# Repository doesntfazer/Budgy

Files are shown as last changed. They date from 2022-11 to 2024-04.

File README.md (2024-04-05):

# Budgy Keyboard

Budgy is a split 34 key keyboard powered by a Raspberry Pi Pico and diode-less.

### Builds:
Budgy  

[Build by: Jakob Edvarsson](https://github.com/JakobEdvardsson)
Budgy

## What you need to build a Budgy

| Component | Amount |
|--|--|
| Reversible Budgy PCB | x2 |
| Raspberry Pi Pico w/headers | x2 |
| Cherry Switches (5 pin recommended) | x34 |
| Keycaps | x34 |
| TRRS Cable | x1 |
| PJ-320A TRRS Jacks | x2 |
| Rubber Bumpers | x8 |

- Solder headers to both raspberry pi Pico's

- On the left hand board, solder the Raspberry Pi Pico facing up and to the rightmost set of pins. If you are still unsure reference the photo above.

- Like in the previous step above, on the right hand side of the board, solder the Pico to the rightmost set of pins. Use the photo for reference. 

- Solder the TRRS Jacks to the top of each side, again reference photo. 

- I recommended at this point, you test the board to make sure everything is functioning. Plug in each side of the board while holding down the reset pin on the top of the board. Drag and drop the UF2 files from [here.](https://github.com/doesntfazer/Keyboard-Dweebs-Firmware-repository/tree/main/VIAL-QMK/budgy) You need to do this on both boards.

- Connect the halves using a TRRS cable, and short each key using some tweezers or a piece of wire. These files use [Vial QMK. You can download this app and use it to configure your keyboard.](https://get.vial.today/download/)

- If everything is working correctly you can proceed to solder in all of the switches, add your keycaps, and put a rubber bumper in each corner on the bottom of each pcb, then start typing away.

### Firmware

Here are links to a couple of different firmware available for the Budgy keyboard. 

- VIAL [here.](https://github.com/doesntfazer/Keyboard-Dweebs-Firmware-repository/tree/main/VIAL-QMK/budgy)
- KMK - [here.](https://github.com/KMKfw/kmk_firmware/tree/master/boards/budgy)
- QMK - [here.](https://github.com/qmk/qmk_firmware/tree/master/keyboards/budgy)

#### Some things to note. 
- It's okay if you don't have 5 pin Cherry switches. If you bend one of the pins on the switch a bit, they should hold in place when you flip the board over.

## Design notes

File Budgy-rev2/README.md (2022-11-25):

# Budgy
 Split 34 key keyboard powered by a raspberry pi pico and QMK

This keyboard is Diodeless. 

DO NOT DOWNLOAD OR PRINT REV 2. I have yet to do any testing. But I noticed a major flaw with the current design. The power supply voltage for the SK6812MINI-E that I am planning to use is 5v (or +3.7~+5.5), and the logic input is 3.3v. I would just use the 3v3 out. But in testing the SK6812MINI-E will not light up under such low power. 

I have added in a voltage divider using 10k + 30k resistor's in an attempt to fix this. This should provide Just enough power (3.75v) to the SK6812MINI-E supply voltage, and be withing the operating range (+-.5v) of the logic input. Although I believe that this fix might work, I don't think that this is the best solution to the problem. 

Another issue is that the VBUS on a rp2040 is directly connected to the 5v usb pin. Some issues can come from this, one being that the power coming from usb is not always consistant. If it doesn't output exactly 5v-5.05v, It will likely either not light, or not be within operating range of the logic input. 

I am going to put rev2 on the backburner for now. If anyone is interested in testing it out in it's current state let me know. But I don't know if I trust it.

Build guide coming soon.

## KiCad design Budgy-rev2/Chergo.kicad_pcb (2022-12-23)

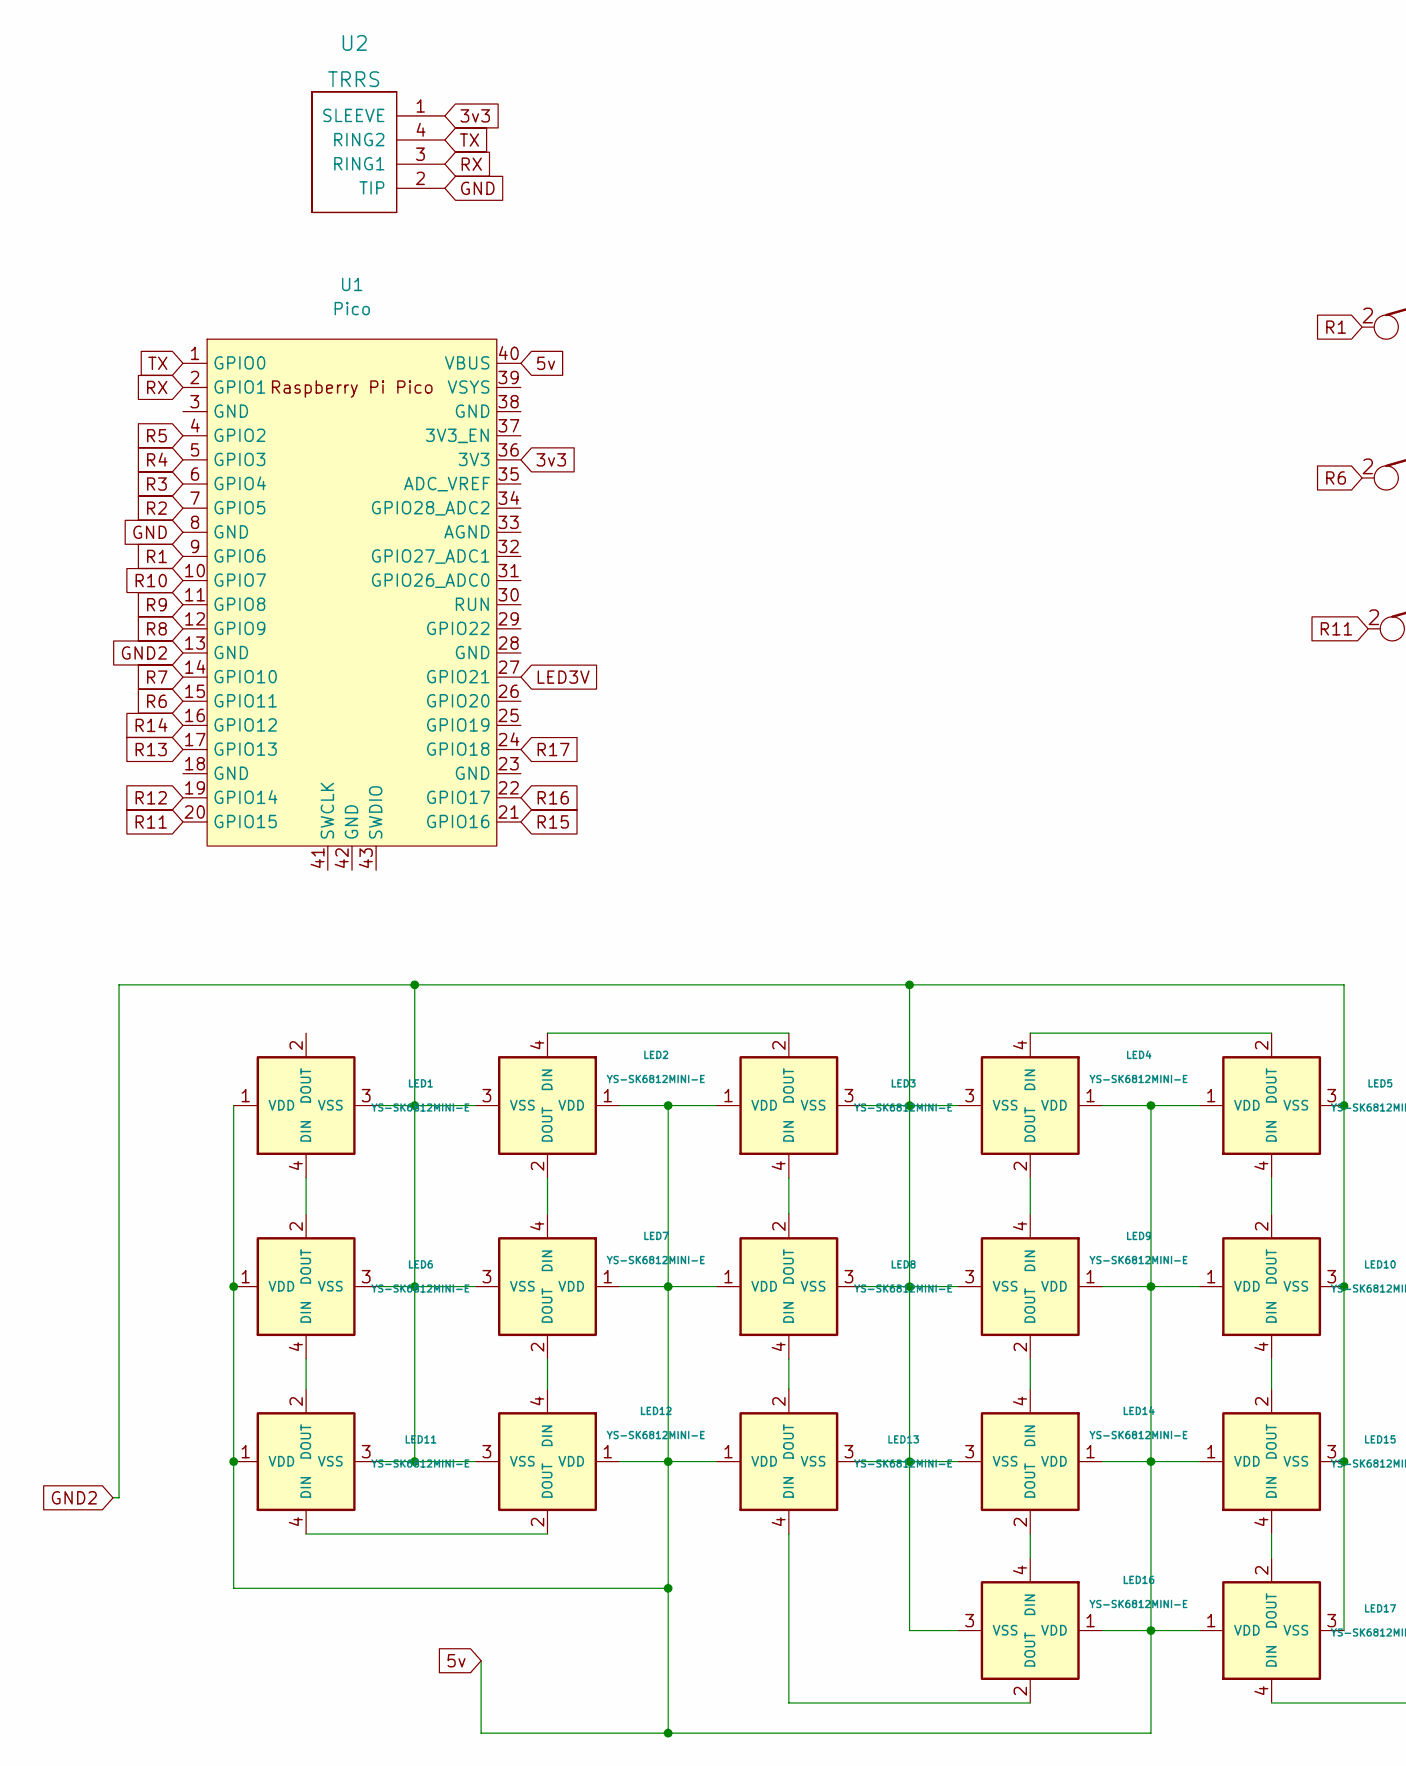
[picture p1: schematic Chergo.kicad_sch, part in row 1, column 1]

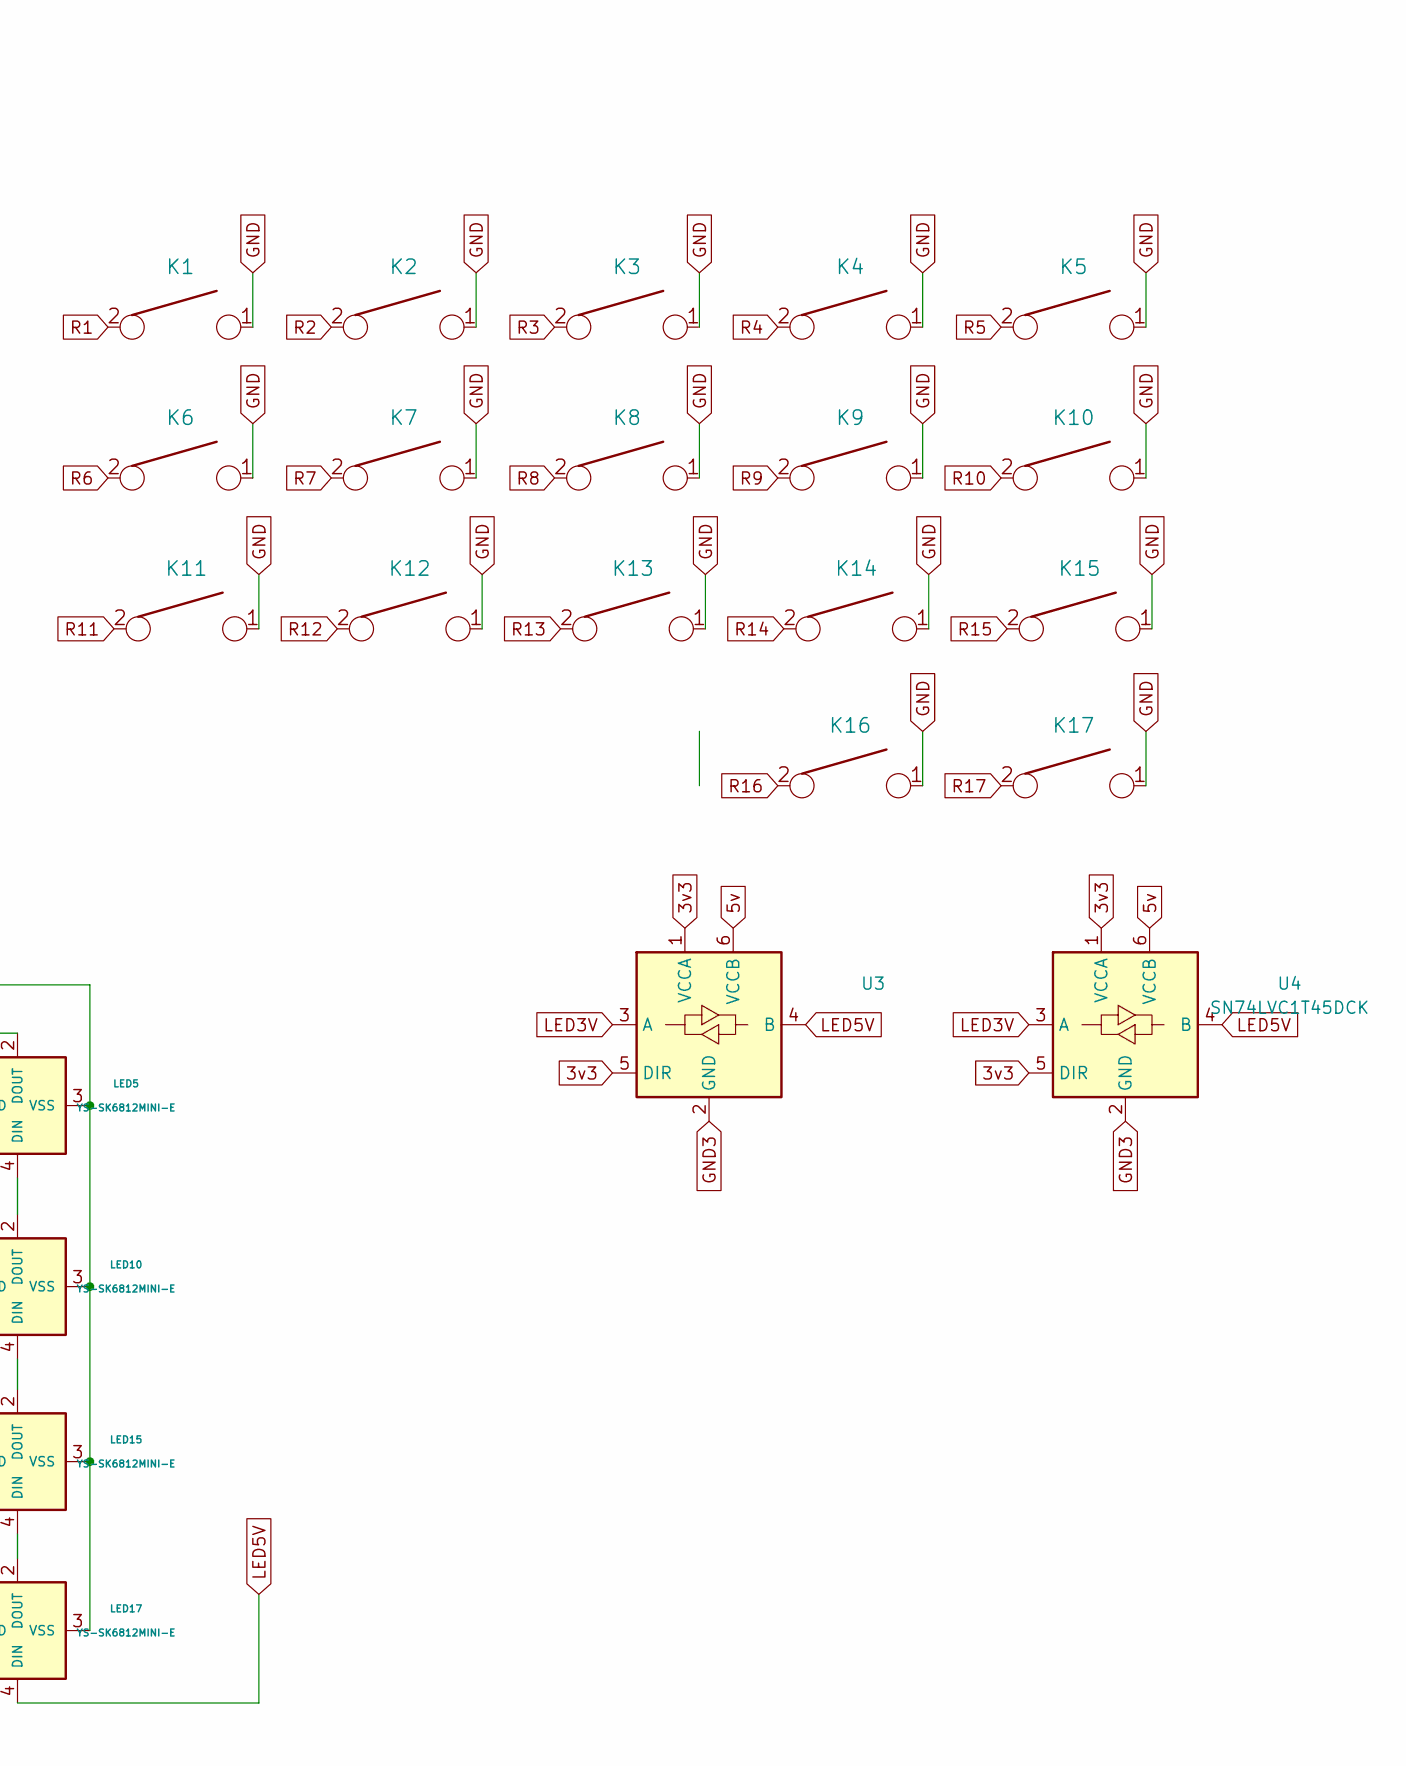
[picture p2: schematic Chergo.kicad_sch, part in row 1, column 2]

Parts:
K1, K2, K3, K4, K5, K6, K7, K8, K9, K10, K11, K12, K13, K14, K15, K16, K17: KEYSW; SW_MX_reversible
LED1, LED2, LED3, LED4, LED5, LED6, LED7, LED8, LED9, LED10, LED11, LED12, LED13, LED14, LED15, LED16, LED17: YS-SK6812MINI-E; YS-SK6812MINI-E-reversible-fix
U1: Pico; RPi_Pico_SMD_TH-REV2
U2: TRRS; TRRS-PJ-320A-rev
U3: (no value)
U4: SN74LVC1T45DCK; SOT-363_SC-70-6

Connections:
3v3: U1.36 (3V3), U2.1 (SLEEVE), U3.1 (VCCA), U3.5 (DIR), U4.1 (VCCA), U4.5 (DIR)
5v: LED1.1 (VDD), LED2.1 (VDD), LED3.1 (VDD), LED4.1 (VDD), LED5.1 (VDD), LED6.1 (VDD), LED7.1 (VDD), LED8.1 (VDD), LED9.1 (VDD), LED10.1 (VDD), LED11.1 (VDD), LED12.1 (VDD), LED13.1 (VDD), LED14.1 (VDD), LED15.1 (VDD), LED16.1 (VDD), LED17.1 (VDD), U1.40 (VBUS), U3.6 (VCCB), U4.6 (VCCB)
GND: K1.1, K2.1, K3.1, K4.1, K5.1, K6.1, K7.1, K8.1, K9.1, K10.1, K11.1, K12.1, K13.1, K14.1, K15.1, K16.1, K17.1, U1.8 (GND), U2.2 (TIP)
GND2: LED1.3 (VSS), LED2.3 (VSS), LED3.3 (VSS), LED4.3 (VSS), LED5.3 (VSS), LED6.3 (VSS), LED7.3 (VSS), LED8.3 (VSS), LED9.3 (VSS), LED10.3 (VSS), LED11.3 (VSS), LED12.3 (VSS), LED13.3 (VSS), LED14.3 (VSS), LED15.3 (VSS), LED16.3 (VSS), LED17.3 (VSS), U1.13 (GND)
GND3: U3.2 (GND), U4.2 (GND)
LED3V: U1.27 (GPIO21), U3.3 (A), U4.3 (A)
LED5V: LED17.4 (DIN), U3.4 (B), U4.4 (B)
unnamed: LED1.4 (DIN), LED6.2 (DOUT)
unnamed: LED2.2 (DOUT), LED7.4 (DIN)
unnamed: LED2.4 (DIN), LED3.2 (DOUT)
unnamed: LED3.4 (DIN), LED8.2 (DOUT)
unnamed: LED4.2 (DOUT), LED9.4 (DIN)
unnamed: LED4.4 (DIN), LED5.2 (DOUT)
unnamed: LED5.4 (DIN), LED10.2 (DOUT)
unnamed: LED10.4 (DIN), LED15.2 (DOUT)
unnamed: LED6.4 (DIN), LED11.2 (DOUT)
unnamed: LED11.4 (DIN), LED12.2 (DOUT)
unnamed: LED7.2 (DOUT), LED12.4 (DIN)
unnamed: LED8.4 (DIN), LED13.2 (DOUT)
unnamed: LED13.4 (DIN), LED16.2 (DOUT)
unnamed: LED14.2 (DOUT), LED16.4 (DIN)
unnamed: LED9.2 (DOUT), LED14.4 (DIN)
unnamed: LED15.4 (DIN), LED17.2 (DOUT)
R1: K1.2, U1.9 (GPIO6)
R2: K2.2, U1.7 (GPIO5)
R3: K3.2, U1.6 (GPIO4)
R4: K4.2, U1.5 (GPIO3)
R5: K5.2, U1.4 (GPIO2)
R6: K6.2, U1.15 (GPIO11)
R7: K7.2, U1.14 (GPIO10)
R8: K8.2, U1.12 (GPIO9)
R9: K9.2, U1.11 (GPIO8)
R10: K10.2, U1.10 (GPIO7)
R11: K11.2, U1.20 (GPIO15)
R12: K12.2, U1.19 (GPIO14)
R13: K13.2, U1.17 (GPIO13)
R14: K14.2, U1.16 (GPIO12)
R15: K15.2, U1.21 (GPIO16)
R16: K16.2, U1.22 (GPIO17)
R17: K17.2, U1.24 (GPIO18)
RX: U1.2 (GPIO1), U2.3 (RING1)
TX: U1.1 (GPIO0), U2.4 (RING2)

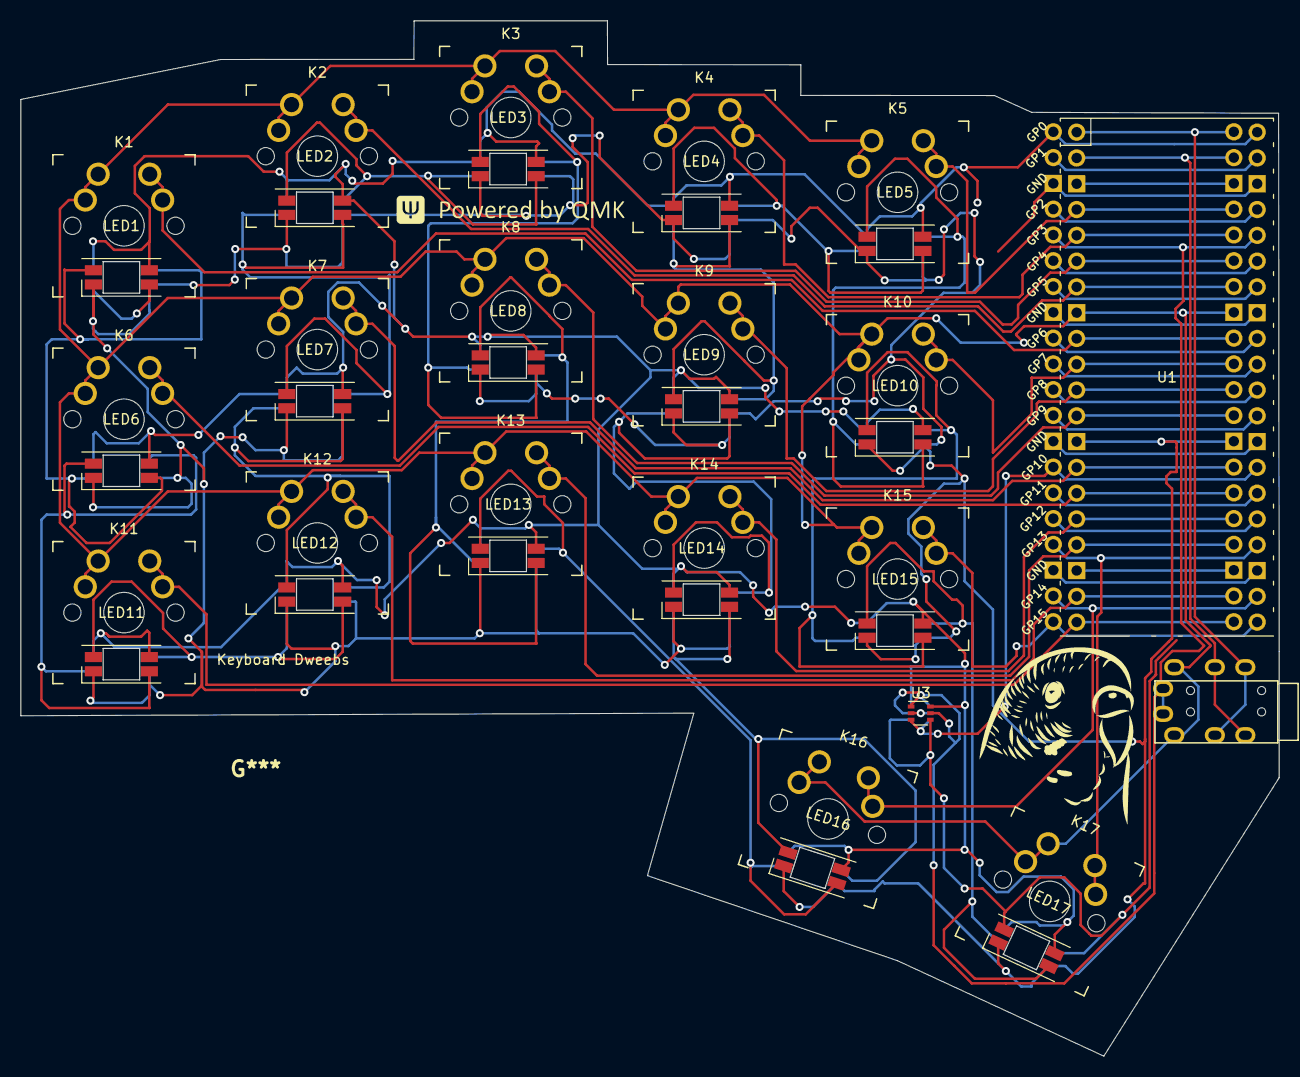
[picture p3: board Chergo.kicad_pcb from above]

Board: 2 copper layers, 124.0 x 102.0 mm, 38 parts (1 on the bottom side), 42 nets.

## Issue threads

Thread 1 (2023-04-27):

Possible LED 5v Logic solution

JellyTitan, 2023-04-27:
In your readme it mentions your having issues with 3.3v logic and the LEDs. I'm working on this issue for my own split. YesterdayI found the Junco readme explicitly details a solve for this using a lower current draw mini-e variant, and a line shifter to bump the logic up from 3.3v to 5v.

I haven't tested the layout myself, but if it's viable this might unblock you on V2.

https://github.com/Daneski13/Junco#optional---rgb

doesntfazer, 2023-04-27:
@JellyTitan I really appreciate you reaching out on this. I actually looked at level shifting as an option. If I remember correctly I was having issues finding in stock level shifters, which was why I was looking at an alternative method. It's been a couple of months since I worked on this, but I might just revisit this.

Closed 2023-04-27.

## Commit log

2022-11-15 added silkscreen
    [Chergo-B_Cu.gbr, Chergo-B_Mask.gbr, Chergo-B_Paste.gbr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]
2022-11-15 silkscreen footprints
2022-11-16 moved to rev1 folder
    [Chergo-B_Cu.gbr, Chergo-B_Mask.gbr, Chergo-B_Paste.gbr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]
2022-11-19 changed to 5v for rgbled
    [Chergo.kicad_pcb, Chergo.kicad_sch]
2022-11-19 added fill zones
    [Chergo.kicad_pcb]
2022-11-25 add voltage divider
    [Chergo.kicad_pcb, Chergo.kicad_sch]
2022-12-23 updates to rev2
    [Chergo.kicad_pcb, Chergo.kicad_sch]
